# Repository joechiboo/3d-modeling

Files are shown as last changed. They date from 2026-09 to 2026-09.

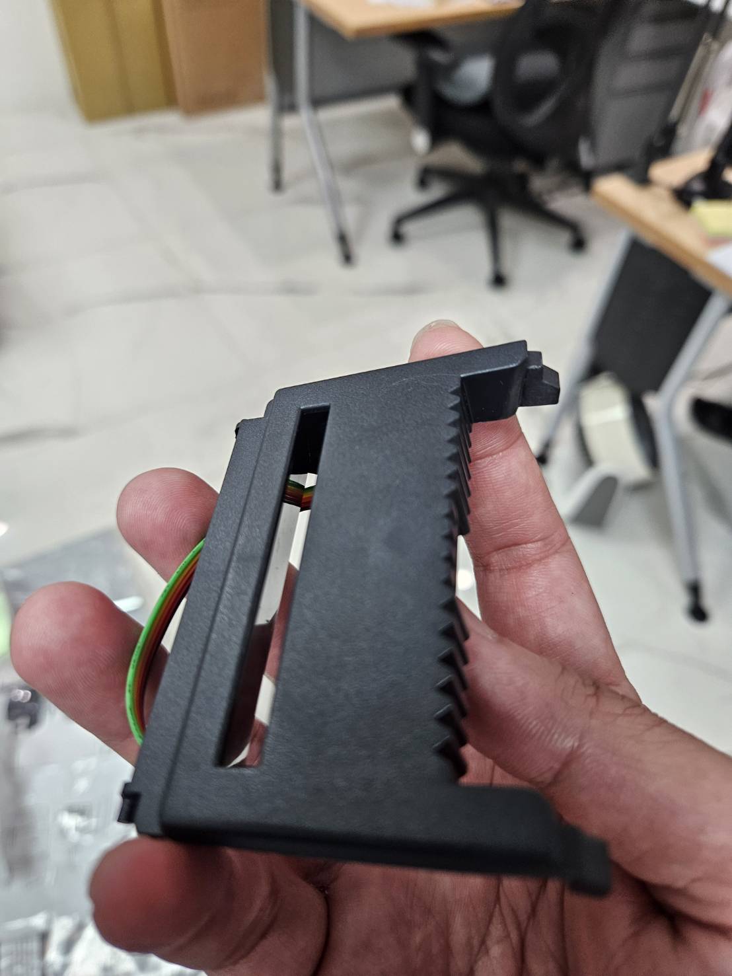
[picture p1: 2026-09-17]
label-parts/photos/module_assembled_outer.jpg

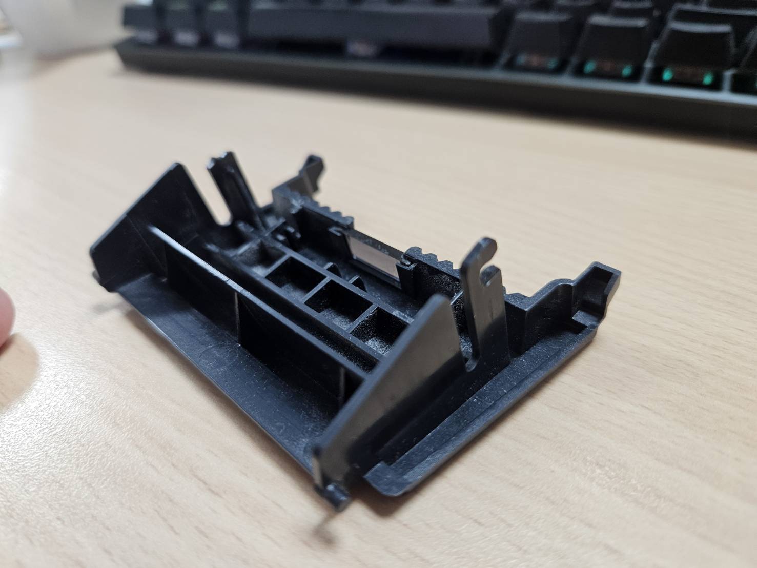
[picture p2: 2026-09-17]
label-parts/photos/peeler_inner_oblique.jpg

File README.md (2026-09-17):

# 3D 建模

個人 3D 建模／列印專案的集合 repo，一個案子一個子目錄。

## 案子

| 案子 | 說明 | 狀態 |
|---|---|---|
| [label-parts](label-parts/) | TSC TDP-225 標籤機撥紙模組替換件 | 階段 1 待試印 |
| [paper-dispenser](paper-dispenser/) | 撥紙器 | 構想中 |

## 子目錄慣例

```
<case-name>/
  README.md      # 需求、尺寸、設計決策
  reference/     # 參考資料、照片、丟進來的 zip 解壓內容
  models/        # 建模檔（.stl / .step / .3mf / .f3d ...）
  docs/          # 量測、列印參數、組裝說明
```

各案子照自己的階段調整（label-parts 用 `peeler/` `stl/` `renders/` `photos/` `scans/`）。
案子長大到需要獨立的 issue / release 節奏時再 split 出去，在那之前都留在這個 repo。

## 慣例

- 模型檔（stl/3mf/step/f3d）與素材在 `.gitattributes` 標成 binary，git 不動換行
- 匯出用的 `*.zip` 不進版控，內容以解壓後的目錄為準

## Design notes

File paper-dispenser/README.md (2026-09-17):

# 撥紙器

## 目的
（待補）

## 現況
- 2026-09-17 建立資料夾，等待參考資料（zip）匯入 `reference/`

## 需求 / 限制
- 尺寸：
- 材料 / 列印方式：
- 使用情境：

## 設計決策
（待補）

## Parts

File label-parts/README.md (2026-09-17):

# label-parts — 標籤機自製零件

TSC TDP-225 系列（貼牌型號 DT2205）的替換／加強零件，3D 列印。
印表機：Bambu（AMS）。目前零件：撥紙模組（peel-off module，原廠料號 98-0390031-00LF）。

## 專案狀態
- 2026-08-20 開工：撥紙器左勾腳斷裂，決定自製加強版
- 2026-09-17 改為階梯式開發：每階只加一個特徵，印小件驗證後再疊
- 原廠件可購買（美國通路 $18.87；TSC 總部在新北新店，可問經銷商）

## 尺寸表 A–M（mm）
| 代號 | 說明 | 值 | 來源 |
|---|---|---|---|
| A | 整體寬（含腳外緣） | 80 | 實測 |
| B | 主體板寬 | 76 | 實測 |
| C | 整體高（正面投影） | 60 | 實測 |
| D | 腳寬 | 8 | 粗估 ⚠ |
| E | 勾伸出量 | 3 | 粗估 ⚠ |
| F | 勾厚 | 2 | 粗估 ⚠ |
| G | 開槽長 | 61.5 | 實測 |
| H | 開槽寬 | 6.5 | 實測 |
| I | 側面低端高 | 10 | 實測 |
| J | 側面高端高 | 26 | 實測 |
| K | 底邊水平長 | 38 | 實測 |
| L | 腳全長 | 18 | 粗估 ⚠ |
| M | 板厚 | 1.5 → 設計 2.5 | 實測＋加厚 |

衍生：斜角 22.8°；斜面真實長 41.2；兩側腳各凸 2。
**尚未量：開槽相對板邊的位置（目前假設在斜面 35% 處）。**

## 階梯計畫
| 階 | 內容 | 驗證重點 | 狀態 |
|---|---|---|---|
| 1 | 斜板＋開槽 | 寬度 76、斜角、槽位 | STL 已出，待印 |
| 2 | 加左右側牆＋高低端牆 | 殼形合機器 | — |
| 3 | 加一支腳（無勾） | 腳的角度 leg_angle、長度 L | — |
| 4 | 加勾 | 卡扣配合，調 E / clr | — |
| 5 | 補強、圓角、PETG 正式版 | 耐用 | — |

## 目錄
- `peeler/` OpenSCAD 原始檔（參數區在檔案開頭）
- `stl/` 輸出 STL（*_flat = 已放平可直接印）
- `renders/` 預覽圖、尺寸示意圖
- `photos/` 實物照片（**看 `photos/INDEX.md`：哪張照片能量哪個尺寸**）
- `scans/` 事務機掃描（目前的是文件模式，網點太重不可描邊；重掃請用照片/灰階模式＋白紙墊背）

## 試印紀錄
| 日期 | 階 | 結果 | 下一步 |
|---|---|---|---|
| | | | |

## 列印建議
斜面朝下平放｜PETG 優先（PLA 可驗尺寸）｜層高 0.2｜周圈 4｜填充 40%｜勾處加支撐

## 指令
```
openscad -o stl/xxx.stl peeler/xxx.scad
openscad -o renders/xxx.png --imgsize=800,600 --camera=38,19,15,55,0,25,300 peeler/xxx.scad
```

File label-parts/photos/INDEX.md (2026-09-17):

# photos/ 索引

命名規則：`<主體>_<面>_<角度/附註>.jpg`
- 主體：`peeler` = 撥紙器本體（要做的零件）；`module` = 整組列印頭模組（裝配脈絡用）
- 面：`outer` = 外側（有鋸齒撕紙邊那面朝上）；`inner` = 內側（有肋條、柱位那面朝上）；`side` = 側視

## peeler — 撥紙器本體

| 檔名 | 內容 | 有尺 | 適合量什麼 |
|---|---|---|---|
| `peeler_outer_top.jpg` | 外側平放俯視，鋸齒邊＋長開槽全景 | ✅ 直尺在左 | G 開槽長、H 開槽寬、**開槽相對板邊位置**（目前唯一未量項） |
| `peeler_outer_front.jpg` | 正面直視，鋸齒朝上，尺平行放在下方 | ✅ 下方 | A 整體寬、B 主體板寬、鋸齒齒距 |
| `peeler_outer_oblique.jpg` | 外側斜角，看得到斜板與兩端勾腳翹起 | ❌ | 斜角 22.8°、整體姿態 |
| `peeler_outer_oblique_ruler.jpg` | 外側斜角＋尺，零件立起 | ✅ 下方 | K 底邊水平長、整體比例 |
| `peeler_inner_top.jpg` | 內側平放俯視，肋條／柱位／模穴痕清楚 | ❌ | 內部補強肋佈局（第 5 階補強用） |
| `peeler_inner_top_ruler.jpg` | 同上＋尺 | ✅ 下方 | A 整體寬、肋條間距 |
| `peeler_inner_top_ruler_rot.jpg` | 內側俯視轉 90°＋尺 | ✅ 左側 | C 整體高方向、肋條深度 |
| `peeler_inner_oblique.jpg` | 內側斜角，看得到肋條高度與腳的根部 | ❌ | 板厚 M、肋高、腳根部形狀 |
| `peeler_side_profile.jpg` | 側視剪影，最能看出斜板折角 | ✅ 左側 | I 低端高、J 高端高、斜角 |
| `peeler_side_hook.jpg` | 端面／勾腳與 L 型卡槽特寫（略糊） | 部分 | D 腳寬、E 勾伸出量、F 勾厚、L 腳全長 ← **全是 ⚠ 粗估項，第 3–4 階要靠這張** |

## module — 列印頭模組（裝配脈絡）

| 檔名 | 內容 |
|---|---|
| `module_assembled_outer.jpg` | 手持，撥紙器裝在模組上的外觀（確認裝配方向） |
| `module_printhead_inner.jpg` | 模組內部：白色膠輥、感測 PCB、排線；撥紙器蓋在其上 |
| `module_in_bag.jpg` | 未拆封備品模組（原廠件對照） |

## 備註
- 原始檔名 `2956xx_0.jpg` 已改名，內容不變；原本的 `part_oblique` / `part_side_oblique` / `part_top_inside` 是其中三張的重複檔，已刪。
- 之後新增照片照同一規則命名，並在本表補一行。

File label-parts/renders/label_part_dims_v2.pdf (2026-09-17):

## 標籤機撥紙器零件 — 尺寸示意圖 v2（已填入現有數值）

* 為照片粗估值，試裝重點微調。示意圖非等比例，單位 mm

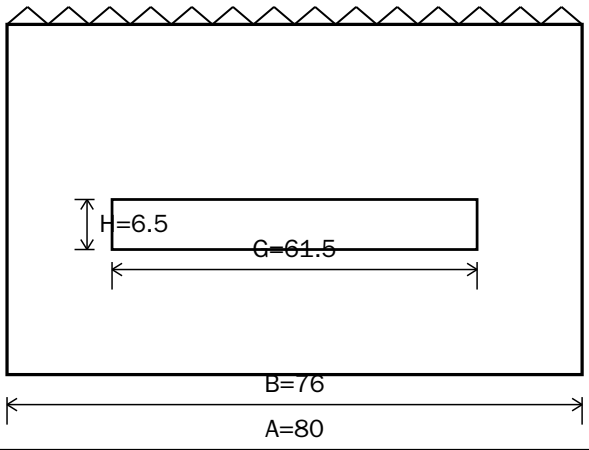
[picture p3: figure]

### 【正面圖】

C=60

D=8*

E=3* 勾伸出
F=2* 勾厚

### 【側面圖】斜角約23°

I=10

J=26

K=38

L=18*

M=1.5→2.5(加厚)

## 數值總表（* = 粗估）

代號 | 說明 | 數值(mm)
A | 整體寬度（含兩側腳外緣） | 80
B | 主體板寬度 | 76
C | 整體高度（正面投影） | 60
D | 腳寬 | 8 *
E | 勾伸出量 | 3 *
F | 勾厚度 | 2 *
G | 中央開槽長度 | 61.5
代號 | 說明 | 數值(mm)
H | 中央開槽寬度 | 6.5
I | 側面低端高度 | 10
J | 側面高端高度 | 26
K | 底邊水平長度 | 38
L | 腳全長（根部到勾尖） | 18 *
M | 主體板厚度 | 1.5 → 2.5

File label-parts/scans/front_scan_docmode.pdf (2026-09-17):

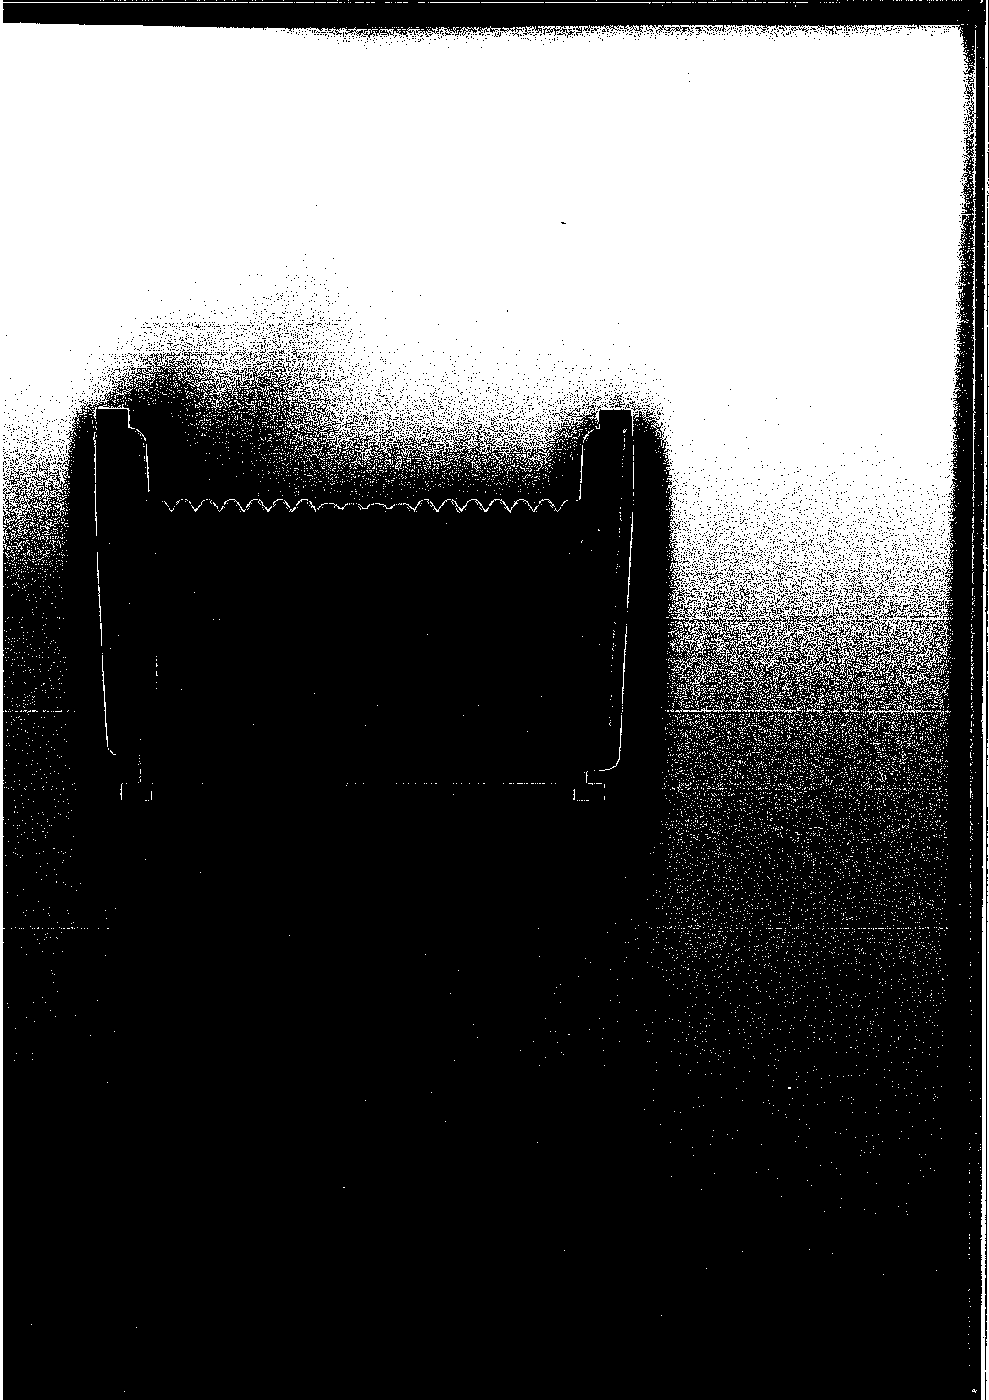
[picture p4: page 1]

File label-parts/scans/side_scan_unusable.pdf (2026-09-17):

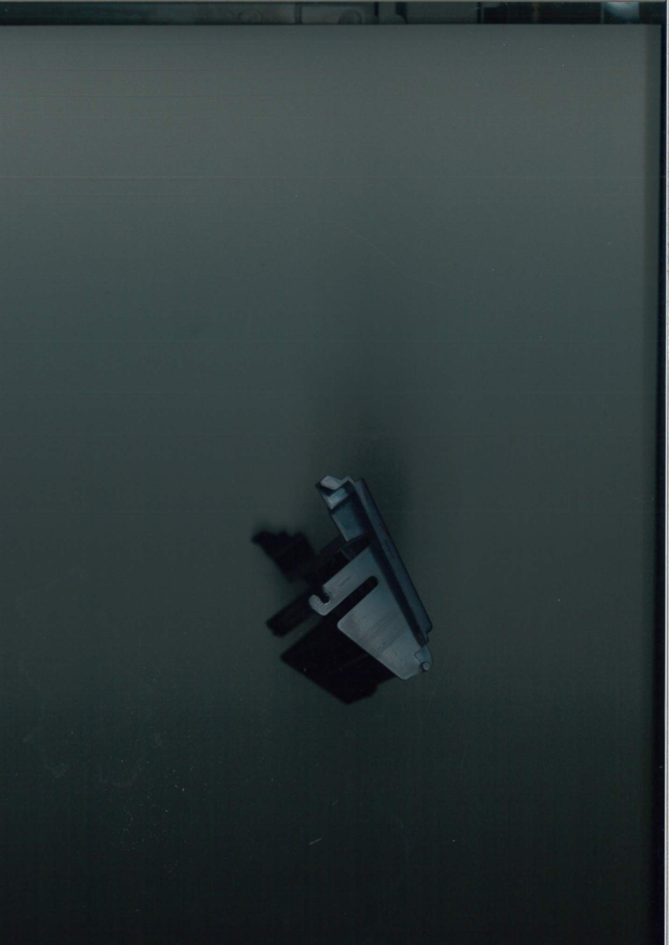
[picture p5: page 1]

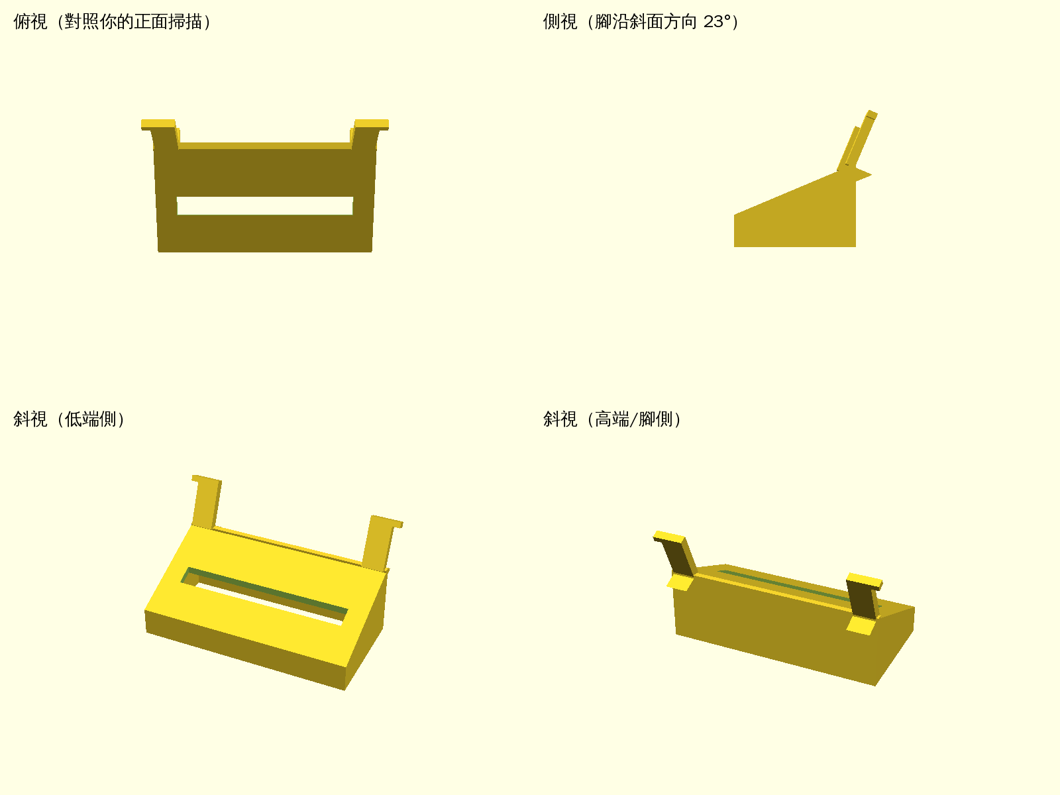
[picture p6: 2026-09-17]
label-parts/renders/peeler_v2_preview.png

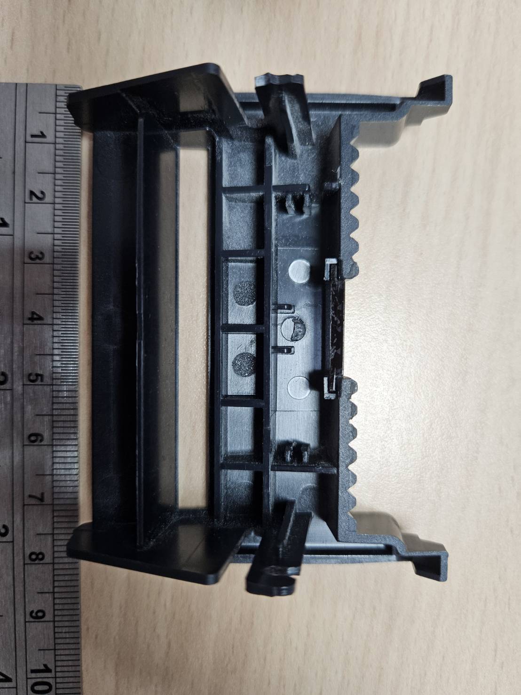
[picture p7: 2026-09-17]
label-parts/photos/peeler_inner_top_ruler_rot.jpg

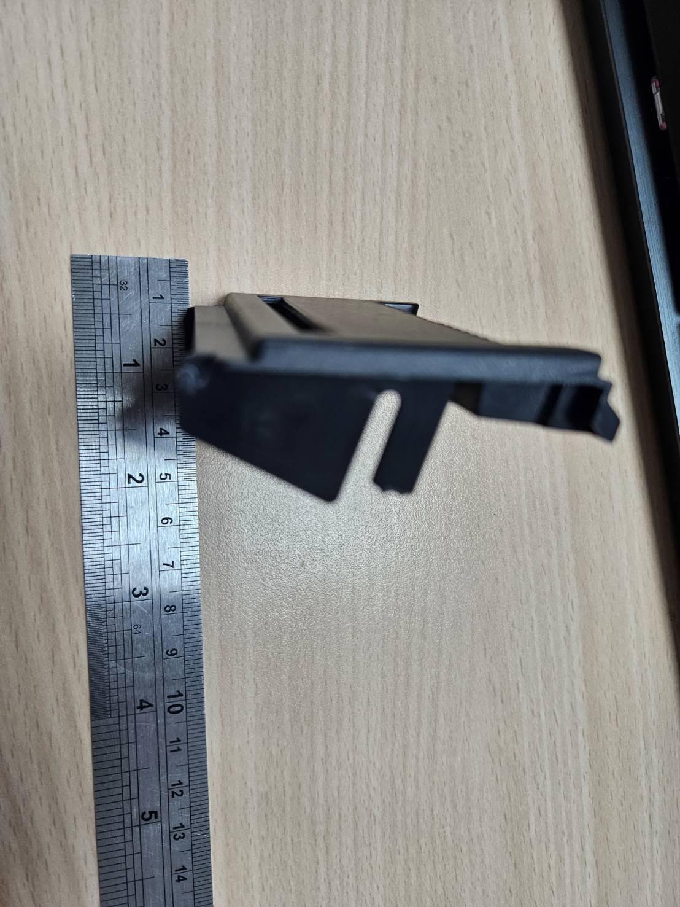
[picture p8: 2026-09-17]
label-parts/photos/peeler_side_profile.jpg

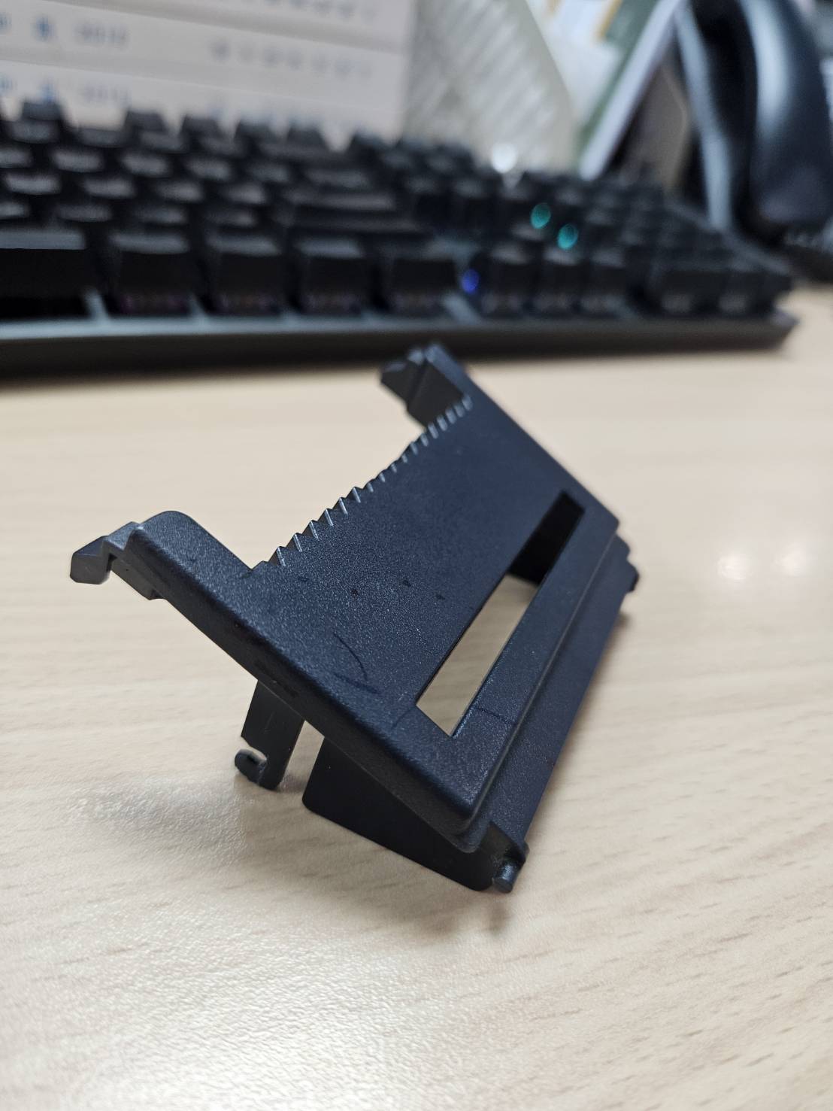
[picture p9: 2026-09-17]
label-parts/photos/peeler_outer_oblique.jpg

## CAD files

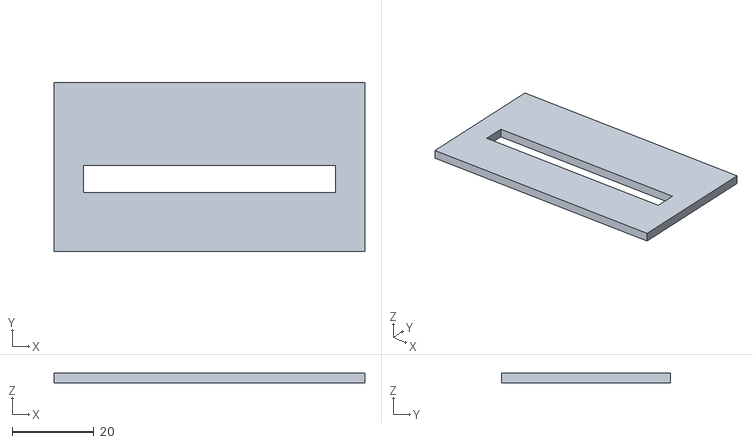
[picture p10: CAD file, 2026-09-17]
label-parts/stl/stage1_plate_flat.stl
76.0 x 41.2 x 2.50

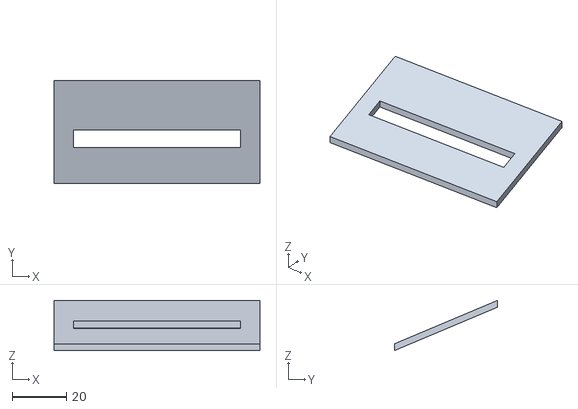
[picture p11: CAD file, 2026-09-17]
label-parts/stl/stage1_plate.stl
76.0 x 38.0 x 18.5

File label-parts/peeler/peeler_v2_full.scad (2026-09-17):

// ============================================================
// TSC TDP-225 (DT2205) 撥紙模組替換件 v2 — 參數化（單位 mm）
// v2 修正：腳改為側牆的延伸、沿斜面方向伸出（可調角度）
// ============================================================

/* ---------- 實測值 ---------- */
A  = 80;    B  = 76;
G  = 61.5;  Hs = 6.5;
Gx = (B-G)/2;
Gy_ratio = 0.35;   // 開槽沿斜面位置 0=低端 1=高端
I  = 10;  J  = 26;  K  = 38;

/* ---------- 粗估值 ---------- */
D  = 8;     // 腳寬（正面看）
E  = 3;     // 勾伸出量（朝外）
F  = 2;     // 勾厚
L  = 18;    // 腳全長
M  = 2.5;   // 板厚（原1.5加厚）

/* ---------- v2 關鍵參數 ---------- */
leg_angle = atan2(J-I, K);  // 腳的傾角：預設=斜面角(23°)，可改 0=垂直
leg_t     = 3;              // 腳厚（側牆延伸的厚度，原件約2，加厚）
wall      = 2;
fillet_r  = 3;
clr       = 0.2;
$fn=32;

/* ============================================================ */
module slab_profile()  { polygon([[0,I],[K,J],[K,J-M],[0,I-M]]); }
module full_profile()  { polygon([[0,0],[K,0],[K,J],[0,I]]); }

module body() {
    difference() {
        union() {
            rotate([90,0,90]) linear_extrude(B) slab_profile();          // 斜板
            rotate([90,0,90]) linear_extrude(wall) full_profile();       // 左側牆
            translate([B-wall,0,0]) rotate([90,0,90]) linear_extrude(wall) full_profile(); // 右側牆
            cube([B, wall, I]);                                          // 低端牆
            translate([0,K-wall,0]) cube([B, wall, J]);                  // 高端牆
        }
        translate([Gx, K*Gy_ratio, -1]) cube([G, Hs, J+2]);              // 開槽
    }
}

// v2 腳：從高端角落沿斜面方向延伸的扁平臂，勾在末端朝外
// 畫在原點：腳身 X 0..D，勾朝 -X 伸出
module leg() {
    rotate([-leg_angle,0,0])
    union() {
        cube([D, leg_t, L]);                          // 腳身
        translate([-(E-clr), 0, L-F])                 // 勾朝外
            cube([E-clr+1, leg_t, F]);
        translate([0,leg_t,0]) rotate([0,90,0]) linear_extrude(D)
            polygon([[0,0],[0,fillet_r*2],[fillet_r*2,0]]);  // 根部補強
    }
}

body();
// 左腳：勾尖對齊整體最外緣（A寬），A 含勾尖
translate([-(A-B)/2 + (E-clr), K-leg_t, J]) leg();
// 右腳：鏡像
translate([B+(A-B)/2 - (E-clr), K-leg_t, J]) mirror([1,0,0]) leg();

/* 列印：斜面朝下平放｜PETG｜0.2層高｜4周圈｜40%填充｜勾加支撐
   leg_angle 改 0 可讓腳變垂直；試裝主要調 E、clr、leg_angle */

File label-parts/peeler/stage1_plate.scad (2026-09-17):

// 第1階：斜板＋開槽（驗證寬度、斜角、槽位）
B=76; K=38; I=10; J=26; M=2.5;
G=61.5; Hs=6.5; Gx=(B-G)/2; Gy=K*0.35;
difference(){
  rotate([90,0,90]) linear_extrude(B) polygon([[0,I],[K,J],[K,J-M],[0,I-M]]);
  translate([Gx,Gy,-1]) cube([G,Hs,J+2]);
}

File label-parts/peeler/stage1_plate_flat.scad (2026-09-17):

B=76; K=38; I=10; J=26; M=2.5;
G=61.5; Hs=6.5; Gx=(B-G)/2;
ang=atan2(J-I,K); Lp=sqrt(K*K+(J-I)*(J-I)); // 斜面真實長度
Gy=Lp*0.35;
// 放平：板子躺在 XY 平面，Y 方向是原本的斜面方向（低端→高端）
difference(){
  cube([B, Lp, M]);
  translate([Gx, Gy, -1]) cube([G, Hs, M+2]);
}
echo(slope_len=Lp, angle=ang);

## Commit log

2026-09-17 初始化 3D 建模專案集合
    - label-parts：TSC TDP-225 撥紙模組替換件，含尺寸表 A–M、OpenSCAD 原始檔、
    階段 1 STL、實物照片與掃描
    - paper-dispenser：撥紙器，構想階段的空殼結構
    - .gitignore 排除匯出用 zip 與切片暫存；.gitattributes 讓模型檔以二進位處理
    [peeler_v2_full.scad, stage1_plate.scad, stage1_plate.stl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]
2026-09-17 README：補上 label-parts、改為單一 repo 的說明
